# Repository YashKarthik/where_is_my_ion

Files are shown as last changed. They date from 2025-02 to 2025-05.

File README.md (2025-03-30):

# Where is my ION???

## LED <-> Driver assignment

1. Driver 1 - 16
    + [x] 1: Conestoga Mall
    + [x] 2: conn to northfield
    + [x] 1: Northfield
    + [x] 3: northfield to r&t
    + [x] 1: R & T
    + [x] 2: r&t to uw
    + [x] 1: UW
    + [x] 1: uw to laurier-waterloo park
    + [x] 1: Laurier-Waterloo Park Stn.
    + [x] 1: laurier-waterloo park to willis way
    + [x] 1: Willis Way Stn.
    + [x] 1: Allen Stn.

2. Driver 2 - 16
    + [x] 1: allen to grh
    + [x] 1: GRH Stn.
    + [x] 2: grh to central
    + [x] 1: Central Stn.
    + [x] 1: Victoria Stn.
    + [x] 1: Queen Stn.
    + [x] 1: Kitchener-Market Stn.
    + [x] 2: kitchener-market to borden
    + [x] 1: Borden Stn.
    + [x] 2: borden to mill
    + [x] 1: Mill Stn.
    + 
    +

3. Driver 3 - 16
    + [x] 3: mill to block line
    + [x] 1: Block Line Stn.
    + [x] 3: block line to fairway
    + [x] 1: Fairway Stn.
-----------reverse
    + [x] 1: Fairway Stn.
    + [x] 3: fairway to block line
    + [x] 1: Block Line Stn.
    + [x] 3: block line to mill

4. Driver 4 - 16
    + [x] 1: Mill Stn.
    + [x] 1: mill to borden
    + [x] 1: Borden Stn.
    + [x] 2: borden to kitchener-market
    + [x] 1: Kitchener-Market Stn.
    + [x] 0: kitchener-market to frederick
    + [x] 1: Frederick Stn.
    + [x] 0: frederick to kitchener city hall
    + [x] 1: Kitchener City Hall Stn.
    + [x] 0: kitchener city hall to central station
    + [x] 1: Central Stn.
    + [x] 2: central to grand river hospital
    + [x] 1: Grand River Hospital Stn.
    + [x] 1: grand river hospital to allen
    + [x] 1: Allen Stn.
    + [x] 0: allen to waterloo public square
    + [x] 1: Waterloo Public Square Stn.
    + [x] 1: waterloo public square to laurier-waterloo park

5. Driver 5 - 14
    + [x] 1: Laurier-Waterloo Park Stn.
    + [x] 1: laurier-waterloo park to university of waterloo
    + [x] 1: University of Waterloo Stn.
    + [x] 2: university of waterloo to research & tech
    + [x] 1: Research & Tech Stn.
    + [x] 3: research & tech to northfield
    + [x] 1: Northfield Stn.
    + [x] 2: northfield to conestoga
    + [x] 1: Conestoga Stn.
    + [x] 1: WIFI (on/off green)

## Num. LED Calculations

- [x] 16 station leds (c -> f) (blue)
- [x] 16 station leds (f -> c) (blue)
- [x] 21 inter-station leds (c -> f) (white)
- [x] 21 inter-station leds (f -> c) (white)
- [x] 1 red/green => 2 leds (power (ON/OFF))
- [x] 1 green wifi (ON/OFF)

= 78/80 used

### Inter-station LEDs

Conestoga to Fairway
- Conestoga to Northfield: 2 leds
- Northfield to Research & Tech: 3 leds
- Research & Tech to University of Waterloo: 2 leds
- University of Waterloo to Laurier-Waterloo Park: 1 led
- Laurier-Waterloo Park to Willis Way: 1 led
- Willis Way to Allen: 0 led
- Allen to Grand River Hospital: 1 led
- Grand River Hospital to Central Station: 2 leds
- Central Station to Victoria Park (0 led)
- Victoria Park to Queen (0 led)
- Queen to Kitchener-Market (0 led)
- Kitchener Market to Borden (2 led)
- Borden to Mill (1 led)
- Mill to Block Line (3 leds)
- Block Line to Fairway (3 ledss)

Fairway to Conestoga
- Fairway to block line (3 leds)
- Block Line to Mill (3 leds)
- Mill to Borden (1 led)
- Borden to Kitchener-Market (2 led)
- Kitchener-Market to Frederick (0 led)
- Frederick to Kitchener City Hall (0 led)
- Kitchener City Hall to Central Station (0 led)
- Central Station to Grand River Hospital:  2 leds
- Grand River Hospital to Allen: 1 led
- Allen to Waterloo Public Sq: 0 led
- Waterloo Public Sq to Laurier-Waterloo Park: 1 led
- Laurier-Waterloo Park to University of Waterloo to : 1 led
- University of Waterloo to Research & Tech:  2 leds
- Research & Tech to Northfield: 3 leds
- Northfield to Conestoga:  2 leds

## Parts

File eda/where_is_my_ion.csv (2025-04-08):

Reference | Qty | Value | DNP | Exclude from BOM | Exclude from Board | Footprint | Datasheet
C1,C8 | 2 | 10 uF/25V |  |  |  | Capacitor_SMD:C_Elec_4x5.4 | ~
C2,C7 | 2 | 1uF/16V |  |  |  | Capacitor_SMD:C_0805_2012Metric | ~
C3,C4 | 2 | 1 uF/50V (NC) |  |  |  | Capacitor_SMD:C_0805_2012Metric | ~
C5 | 1 | 10uF/25V |  |  |  | Capacitor_SMD:C_Elec_4x5.4 | ~
C6 | 1 | 0.1uF/50V |  |  |  | Capacitor_SMD:C_0603_1608Metric | ~
C9,C14 | 2 | 0.1 uF/50V |  |  |  | Capacitor_SMD:C_0603_1608Metric | ~
C10,C11,C16,C17,C18 | 5 | 0.1uF ceramic |  |  |  | Capacitor_SMD:C_0603_1608Metric | ~
C12,C13,C19,C20,C21 | 5 | 10uF |  |  |  | Capacitor_SMD:C_Elec_4x5.4 | ~
C15 | 1 | 10 uFF/25V |  |  |  | Capacitor_SMD:C_Elec_4x5.4 | ~
D1,D2,D3 | 3 | D_TVS_Filled |  |  |  | Diode_SMD:D_SOD-523 | ~
D4 | 1 | D |  |  |  | Diode_SMD:D_SOD-123 | ~
D5,D6,D7,D10,D11,D12,D16,D19,D20,D21,D22,D28,D33,D34,D37,D39,D46,D47,D52,D53,D54,D55,D57,D62,D65,D70,D81,D82,D83,D84 | 30 | LED_STN_BLUE |  |  |  | LED_SMD:LED_0603_1608Metric | ~
D8 | 1 | LED_FETCH_GREEN |  |  |  | LED_SMD:LED_0603_1608Metric | ~
D9,D13,D14,D15,D17,D18,D23,D24,D25,D26,D29,D30,D31,D32,D35,D36,D38,D40,D41,D44,D45,D48,D50,D51,D56,D58,D59,D60,D61,D63,D64,D66,D67,D68,D69,D71,D72,D73,D74,D75,D76,D77,D78,D79,D80 | 45 | LED_INTER_WHITE |  |  |  | LED_SMD:LED_0603_1608Metric | ~
D27 | 1 | RED POWER LED |  |  |  | LED_SMD:LED_0603_1608Metric | ~
D42 | 1 | LED_API_FAIL_RED |  |  |  | LED_SMD:LED_0603_1608Metric | ~
D43 | 1 | LED_MAP_MODE_GREEN |  |  |  | LED_SMD:LED_0603_1608Metric | ~
D49 | 1 | LED_GREEN_WIFI |  |  |  | LED_SMD:LED_0603_1608Metric | ~
J1 | 1 | USB_C_Receptacle_USB2.0_14P |  |  |  | Connector_USB:USB_C_Receptacle_HRO_TYPE-C-31-M-12 | https://www.usb.org/sites/default/files/documents/usb_type-c.zip
Q1,Q2 | 2 | L8050QLT1G |  |  |  | Package_TO_SOT_SMD:TSOT-23 | ~
R1 | 1 | 22.1 K |  |  |  | Resistor_SMD:R_0603_1608Metric | ~
R2 | 1 | 47.5K |  |  |  | Resistor_SMD:R_0603_1608Metric | ~
R3 | 1 | 1K |  |  |  | Resistor_SMD:R_0603_1608Metric | ~
R4,R5,R13,R21 | 4 | 10K |  |  |  | Resistor_SMD:R_0603_1608Metric | ~
R6,R7 | 2 | 5.1K |  |  |  | Resistor_SMD:R_0603_1608Metric | ~
R8,R9 | 2 | 0 |  |  |  | Resistor_SMD:R_0603_1608Metric | ~
R10 | 1 | 10K (NC) |  |  |  | Resistor_SMD:R_0603_1608Metric | ~
R11,R12 | 2 | 4.7K |  |  |  | Resistor_SMD:R_0603_1608Metric | ~
R14,R15,R16,R17 | 4 | 0(1%) |  |  |  | Resistor_SMD:R_0603_1608Metric | ~
R18,R19,R23,R24,R25 | 5 | 931R |  |  |  | Resistor_SMD:R_0603_1608Metric | ~
R20 | 1 | R |  |  |  | Resistor_SMD:R_0603_1608Metric | ~
R22 | 1 | 5.1 K |  |  |  | Resistor_SMD:R_0603_1608Metric | ~
SW1 | 1 | SW_MCU_RESET |  |  |  | TS-1088-AR02016:SW_TS-1088-AR02016_1 | ~
SW2 | 1 | SW_BOOT_SEL |  |  |  | TS-1088-AR02016:SW_TS-1088-AR02016_1 | ~
SW3 | 1 | FORCE_REFRESH |  |  |  | TS-1088-AR02016:SW_TS-1088-AR02016_1 | ~
SW4 | 1 | NEXT_TRAIN |  |  |  | TS-1088-AR02016:SW_TS-1088-AR02016_1 | ~
TP1,TP2,TP3,TP4 | 4 | TestPoint |  |  |  | TestPoint:TestPoint_Pad_D2.0mm | ~
U1 | 1 | CP2102N-Axx-xQFN28 |  |  |  | Package_DFN_QFN:QFN-28-1EP_5x5mm_P0.5mm_EP3.35x3.35mm | https://www.silabs.com/documents/public/data-sheets/cp2102n-datasheet.pdf
U2,U3,U6,U7,U8 | 5 | TLC59116IPWR |  |  |  | TLC59116IPWR:SOP65P640X120-28N
U4 | 1 | ESP32-C3-WROOM-02 |  |  |  | RF_Module:ESP32-C3-WROOM-02 | https://www.espressif.com/sites/default/files/documentation/esp32-c3-wroom-02_datasheet_en.pdf
U5 | 1 | AP2112K-3.3 |  |  |  | Package_TO_SOT_SMD:SOT-23-5 | https://www.diodes.com/assets/Datasheets/AP2112.pdf

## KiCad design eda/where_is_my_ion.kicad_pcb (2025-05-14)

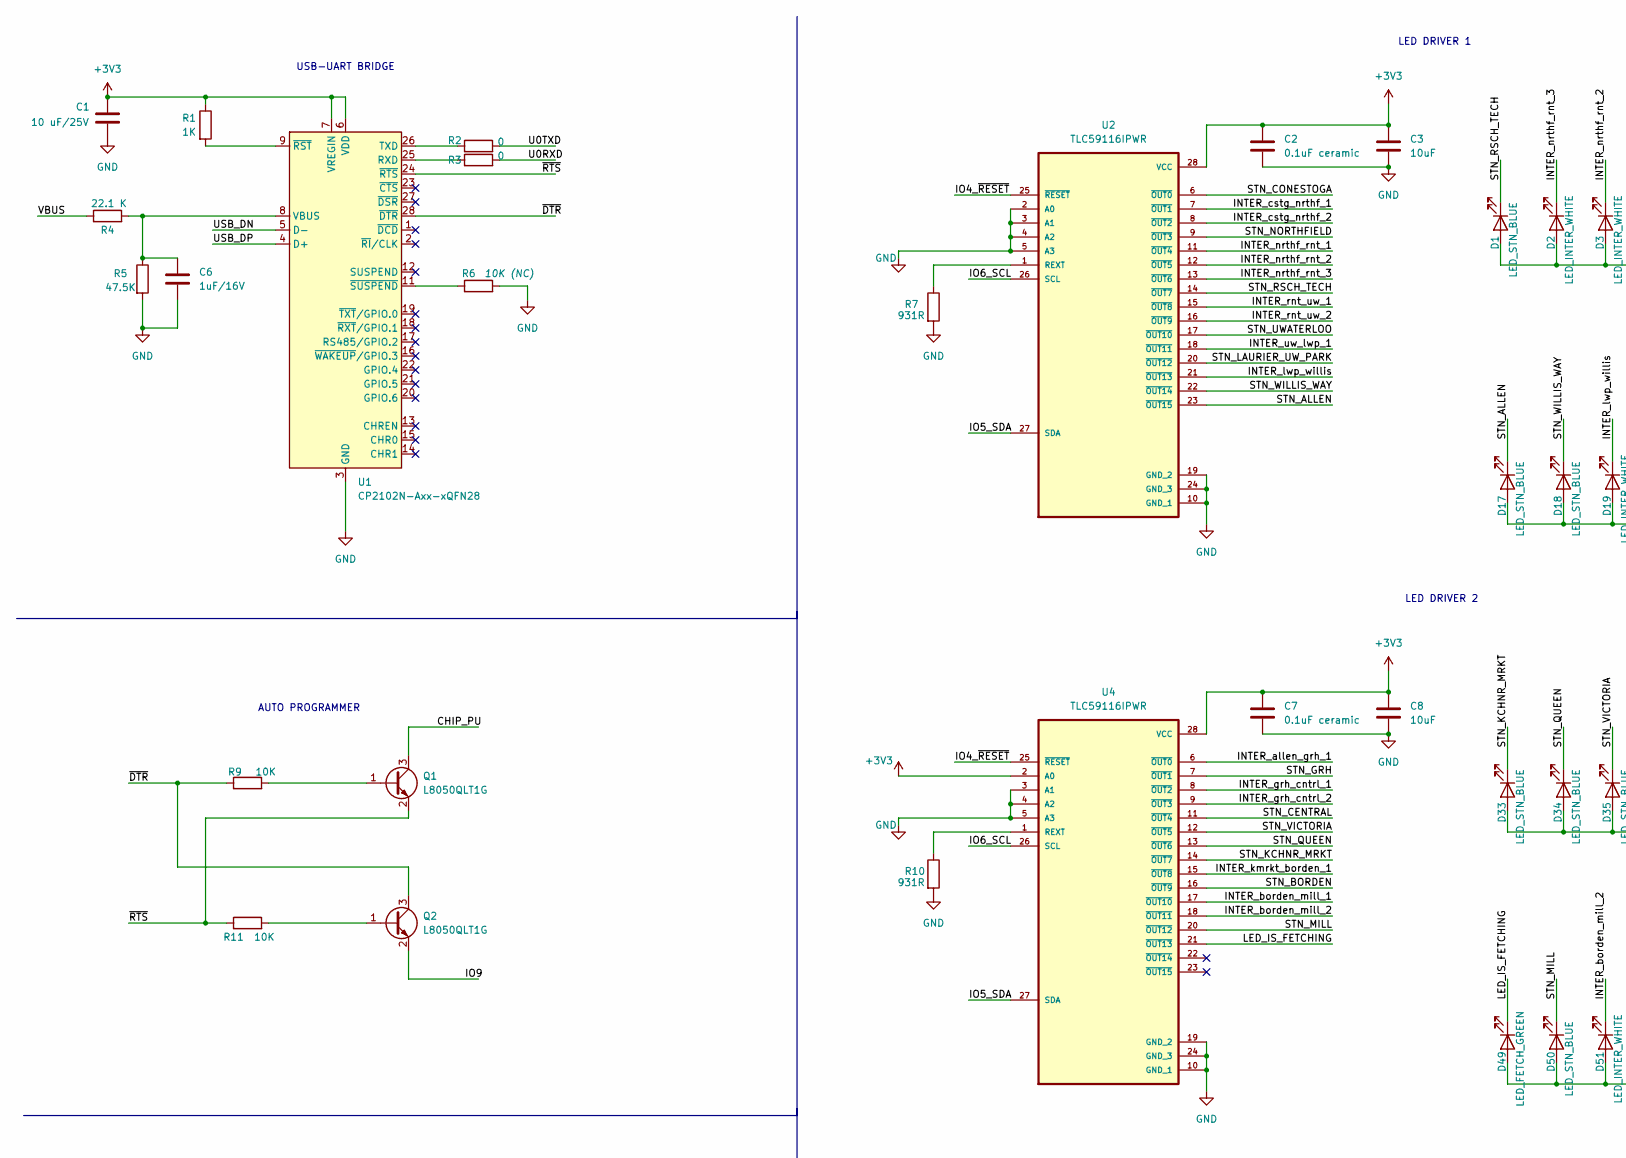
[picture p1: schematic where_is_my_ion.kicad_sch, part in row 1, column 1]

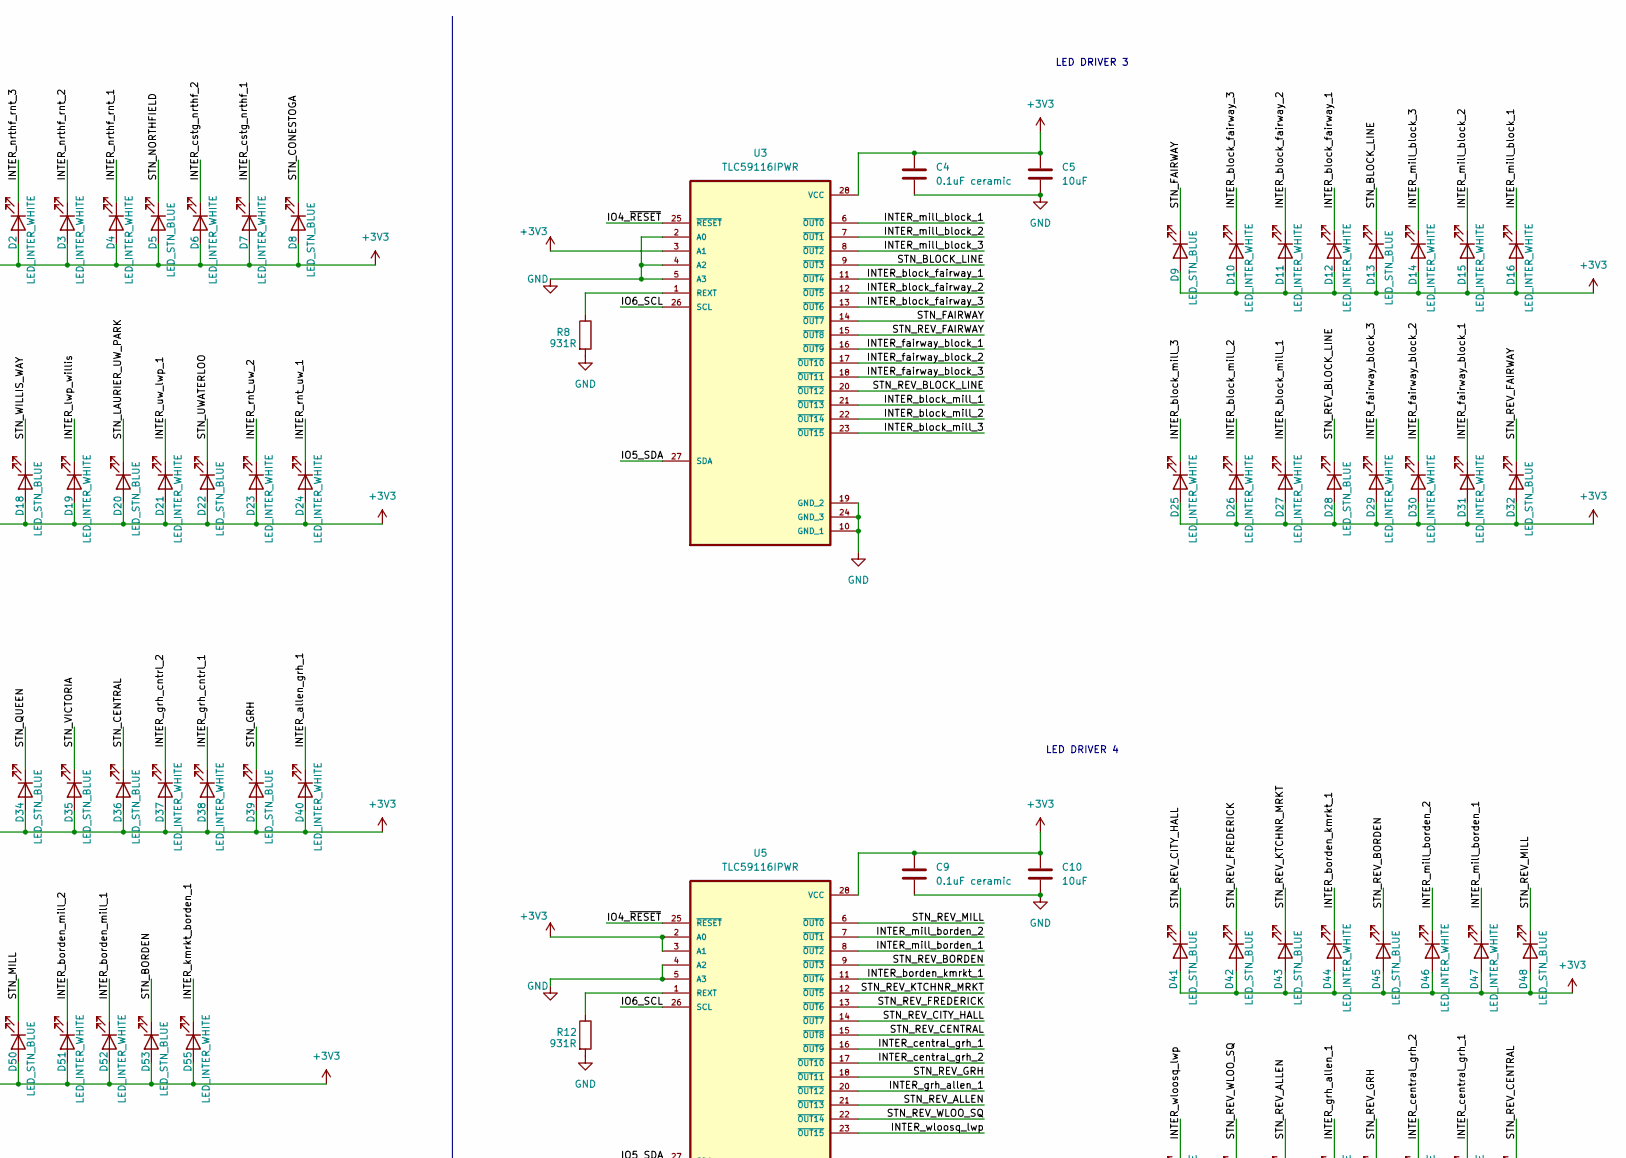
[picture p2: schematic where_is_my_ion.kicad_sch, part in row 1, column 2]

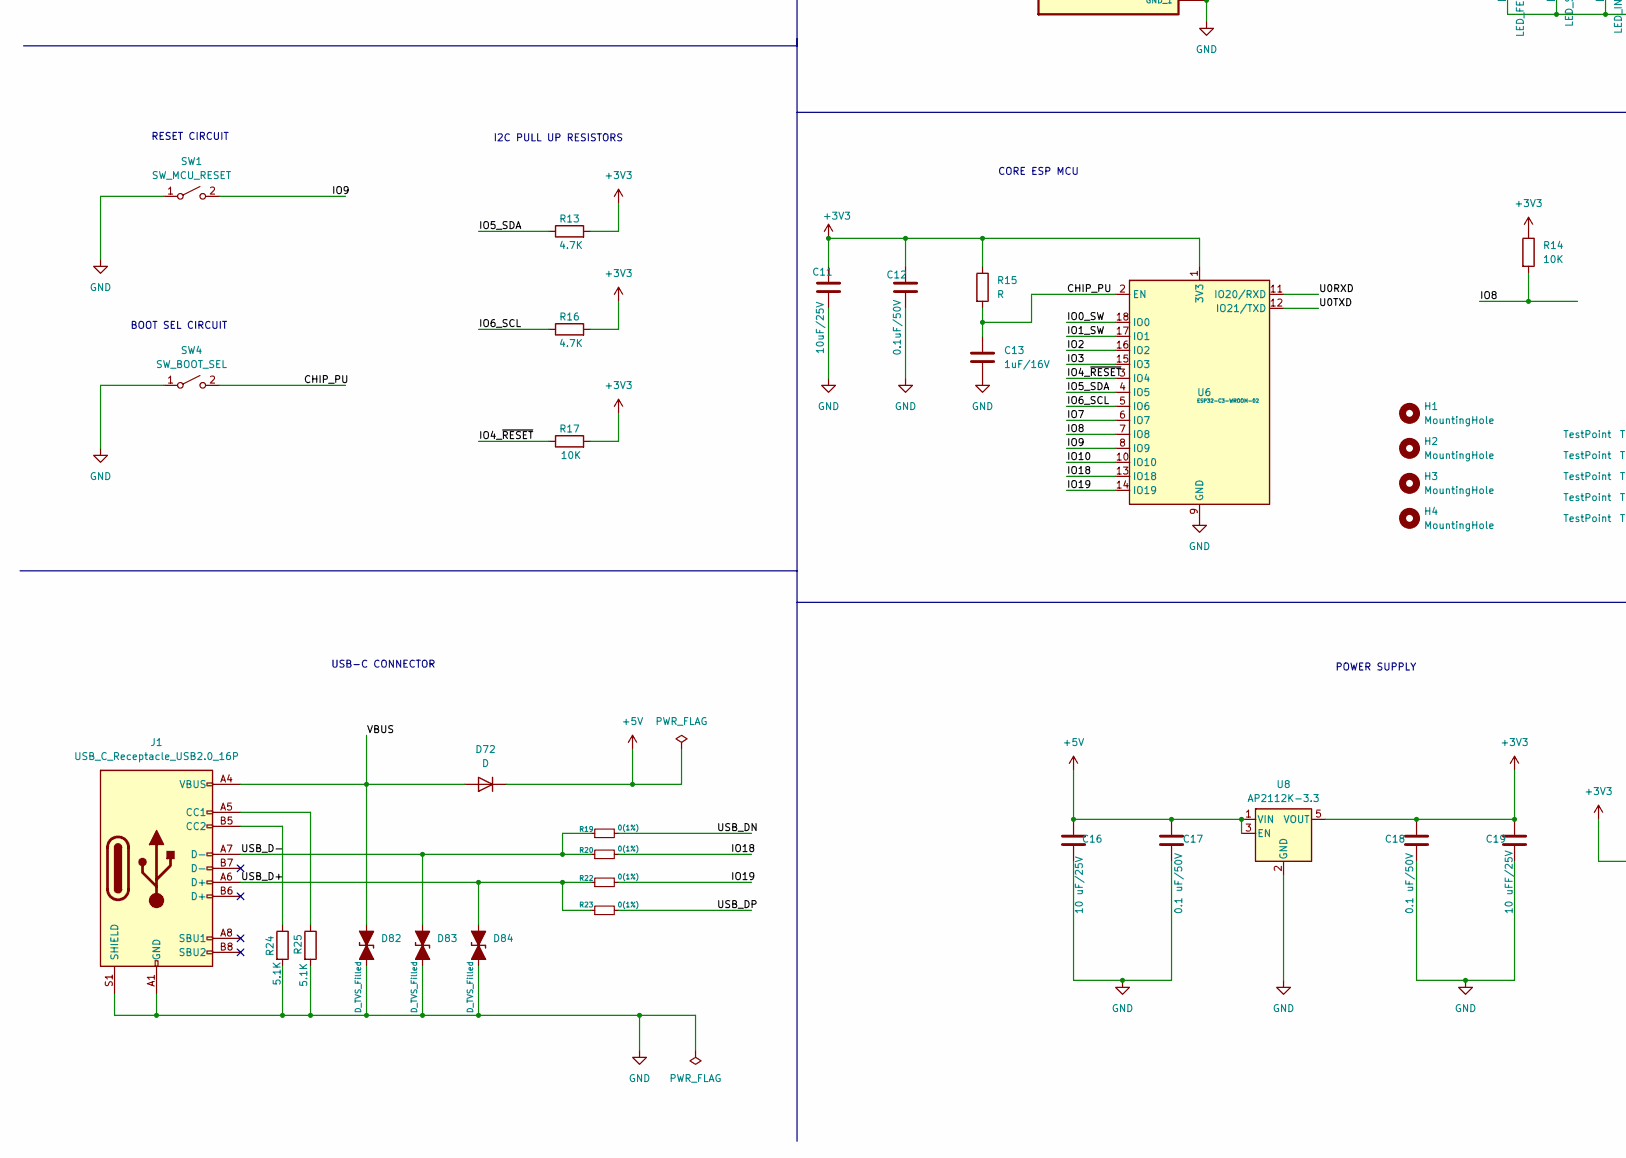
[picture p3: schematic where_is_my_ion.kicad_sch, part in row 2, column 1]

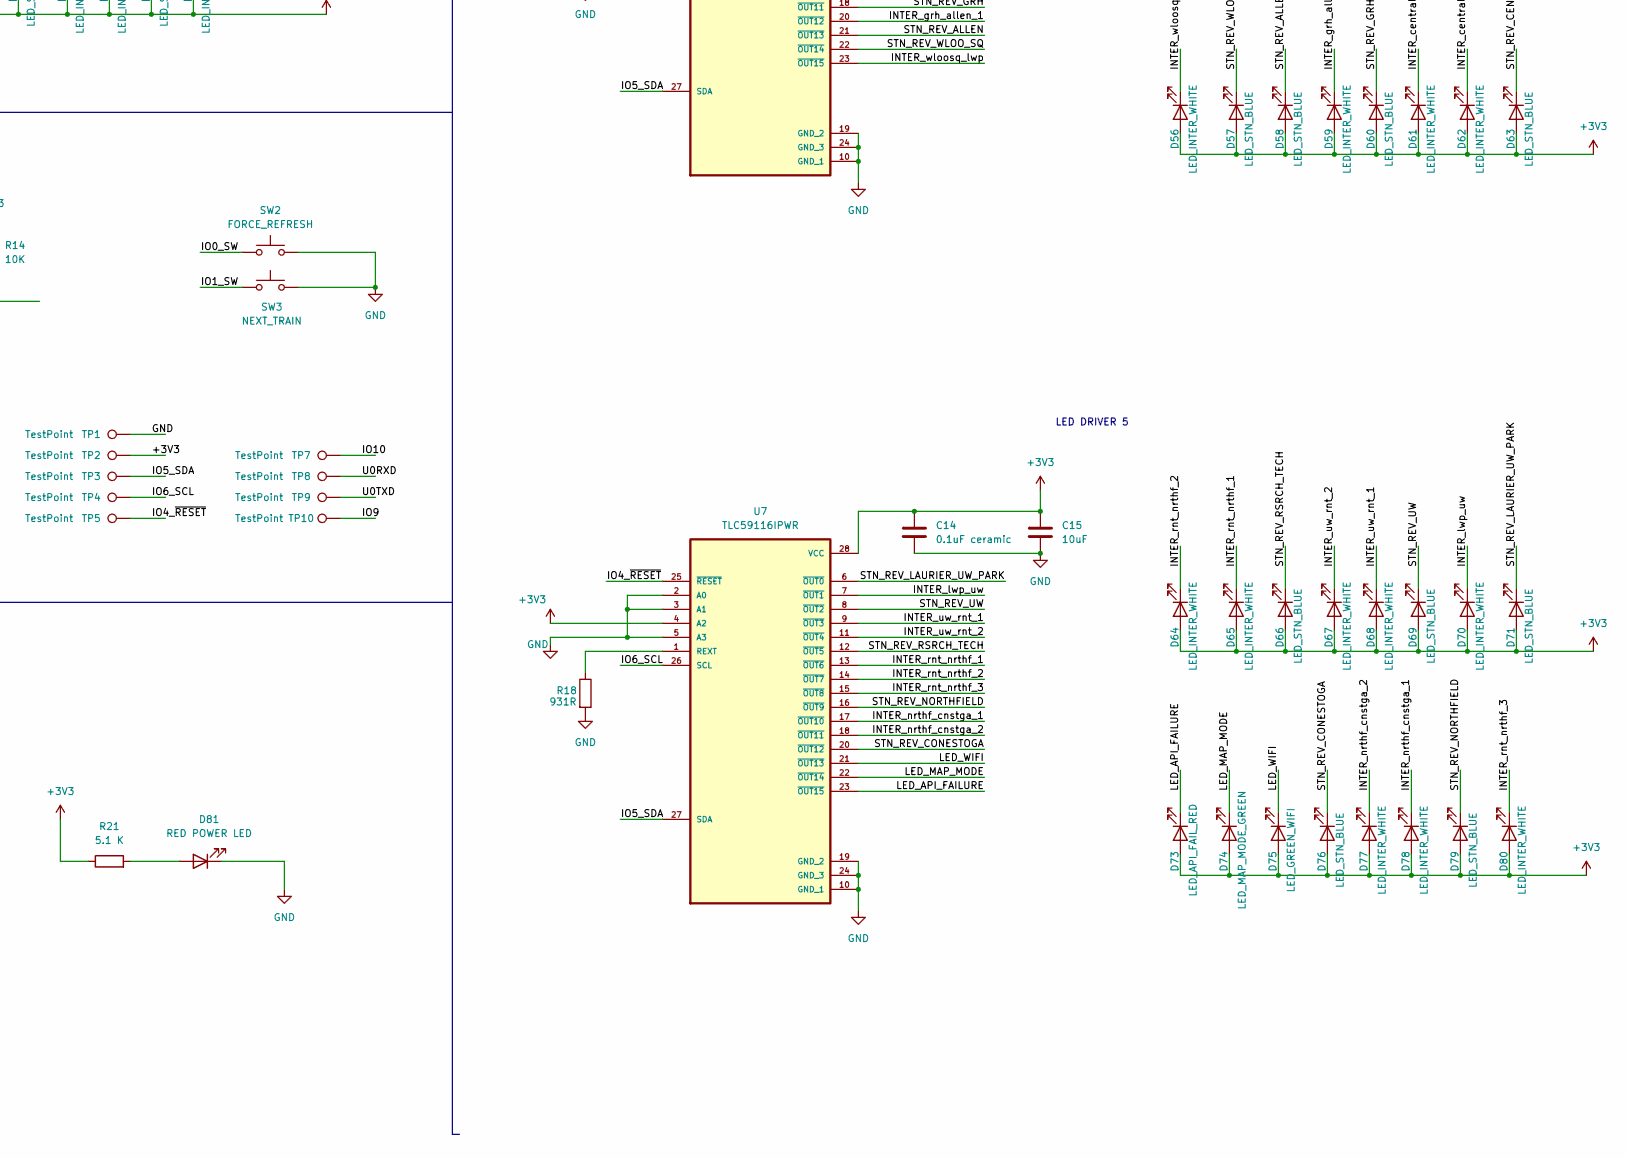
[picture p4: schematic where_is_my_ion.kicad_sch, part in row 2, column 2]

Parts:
C1: 10 uF/25V; CP_EIA-3528-15_AVX-H; LCSC Part Num. C22387953
C2, C4, C7, C9, C14: 0.1uF ceramic; C_0603_1608Metric
C3, C5, C8, C10, C15: 10uF; CP_EIA-3528-15_AVX-H
C6, C13: 1uF/16V; C_0805_2012Metric; LCSC Part Num. C24123
C11: 10uF/25V; CP_EIA-3528-15_AVX-H; LCSC Part Num. C22387953
C12: 0.1uF/50V; C_0603_1608Metric; LCSC Part Num. C3011652
C16: 10 uF/25V; CP_EIA-3528-15_AVX-H
C17, C18: 0.1 uF/50V; C_0603_1608Metric
C19: 10 uFF/25V; CP_EIA-3528-15_AVX-H
D1: LED_STN_BLUE; LED_0603_1608Metric; LCSC Part Num. C497940
D2: LED_INTER_WHITE; LED_0603_1608Metric; LCSC Part Num. C965808
D3, D4, D6, D7, D10, D11, D12, D14, D15, D16, D19, D21, D23, D24, D25, D26, D27, D29, D30, D31, D37, D38, D40, D44, D46, D47, D51, D52, D55, D56, D59, D61, D62, D64, D65, D67, D68, D70, D77, D78, D80: LED_INTER_WHITE; LED_0603_1608Metric
D5, D8, D9, D13, D17, D18, D20, D22, D28, D32, D33, D34, D35, D36, D39, D41, D42, D43, D45, D48, D50, D53, D57, D58, D60, D63, D66, D69, D71, D76, D79: LED_STN_BLUE; LED_0603_1608Metric
D49: LED_FETCH_GREEN; LED_0603_1608Metric; LCSC Part Num. C7429914
D72: D; D_SOD-123; LCSC Part Num. C82544
D73: LED_API_FAIL_RED; LED_0603_1608Metric
D74: LED_MAP_MODE_GREEN; LED_0603_1608Metric
D75: LED_GREEN_WIFI; LED_0603_1608Metric
D81: RED POWER LED; LED_0603_1608Metric; LCSC Part Num. C965799
D82: D_TVS_Filled; D_SOD-523; LCSC Part Num. C383211
D83, D84: D_TVS_Filled; D_SOD-523
H1, H2, H3, H4: MountingHole; MountingHole_2.2mm_M2
J1: USB_C_Receptacle_USB2.0_16P; USB_C_Receptacle_HRO_TYPE-C-31-M-12
Q1, Q2: L8050QLT1G; SOT-23
R1: 1K; R_0603_1608Metric; LCSC Part Num. C22548
R2, R3: 0; R_0603_1608Metric
R4: 22.1 K; R_0603_1608Metric; LCSC Part Num. C137768
R5: 47.5K; R_0603_1608Metric; LCSC Part Num. C2933225
R6: 10K (NC); R_0603_1608Metric
R7, R8, R10, R12, R18: 931R; R_0603_1608Metric
R9, R11, R14, R17: 10K; R_0603_1608Metric
R13, R16: 4.7K; R_0603_1608Metric
R15: R; R_0603_1608Metric
R19, R20, R22, R23: 0(1%); R_0603_1608Metric
R21: 5.1 K; R_0603_1608Metric
R24, R25: 5.1K; R_0603_1608Metric
SW1: SW_MCU_RESET; SW_TS-1088-AR02016_1
SW2: FORCE_REFRESH; SW_TS-1088-AR02016_1
SW3: NEXT_TRAIN; SW_TS-1088-AR02016_1
SW4: SW_BOOT_SEL; SW_TS-1088-AR02016_1
TP1, TP2, TP3, TP4, TP5, TP7, TP8, TP9, TP10: TestPoint; TestPoint_Pad_D2.0mm
U1: CP2102N-Axx-xQFN28; QFN-28-1EP_5x5mm_P0.5mm_EP3.35x3.35mm
U2, U3, U4, U5, U7: TLC59116IPWR; SOP65P640X120-28N
U6: ESP32-C3-WROOM-02
U8: AP2112K-3.3; SOT-23-5

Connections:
+3V3: C1.1, C2.1, C3.1, C4.1, C5.1, C7.1, C8.1, C9.1, C10.1, C11.1, C12.1, C14.1, C15.1, C18.2, C19.1, D1.2 (A), D2.2 (A), D3.2 (A), D4.2 (A), D5.2 (A), D6.2 (A), D7.2 (A), D8.2 (A), D9.2 (A), D10.2 (A), D11.2 (A), D12.2 (A), D13.2 (A), D14.2 (A), D15.2 (A), D16.2 (A), D17.2 (A), D18.2 (A), D19.2 (A), D20.2 (A), D21.2 (A), D22.2 (A), D23.2 (A), D24.2 (A), D25.2 (A), D26.2 (A), D27.2 (A), D28.2 (A), D29.2 (A), D30.2 (A), D31.2 (A), D32.2 (A), D33.2 (A), D34.2 (A), D35.2 (A), D36.2 (A), D37.2 (A), D38.2 (A), D39.2 (A), D40.2 (A), D41.2 (A), D42.2 (A), D43.2 (A), D44.2 (A), D45.2 (A), D46.2 (A), D47.2 (A), D48.2 (A), D49.2 (A), D50.2 (A), D51.2 (A), D52.2 (A), D53.2 (A), D55.2 (A), D56.2 (A), D57.2 (A), D58.2 (A), D59.2 (A), D60.2 (A), D61.2 (A), D62.2 (A), D63.2 (A), D64.2 (A), D65.2 (A), D66.2 (A), D67.2 (A), D68.2 (A), D69.2 (A), D70.2 (A), D71.2 (A), D73.2 (A), D74.2 (A), D75.2 (A), D76.2 (A), D77.2 (A), D78.2 (A), D79.2 (A), D80.2 (A), R1.1, R13.2, R14.1, R15.1, R16.2, R17.2, R21.1, TP2.1, U1.6 (VDD), U1.7 (VREGIN), U2.28 (VCC), U3.3 (A1), U3.28 (VCC), U4.2 (A0), U4.28 (VCC), U5.2 (A0), U5.3 (A1), U5.28 (VCC), U6.1 (3V3), U7.4 (A2), U7.28 (VCC), U8.5 (VOUT)
+5V: C16.1, C17.2, D72.1 (K), U8.1 (VIN), U8.3 (EN)
/CHIP_PU: C13.1, Q1.3 (C), R15.2, SW4.2 (B), U6.2 (EN)
/INTER_allen_grh_1: D40.1 (K), U4.6 (~OUT0)
/INTER_block_fairway_1: D12.1 (K), U3.11 (~OUT4)
/INTER_block_fairway_2: D11.1 (K), U3.12 (~OUT5)
/INTER_block_fairway_3: D10.1 (K), U3.13 (~OUT6)
/INTER_block_mill_1: D27.1 (K), U3.21 (~OUT13)
/INTER_block_mill_2: D26.1 (K), U3.22 (~OUT14)
/INTER_block_mill_3: D25.1 (K), U3.23 (~OUT15)
/INTER_borden_kmrkt_1: D44.1 (K), U5.11 (~OUT4)
/INTER_borden_mill_1: D52.1 (K), U4.17 (~OUT10)
/INTER_borden_mill_2: D51.1 (K), U4.18 (~OUT11)
/INTER_central_grh_1: D62.1 (K), U5.16 (~OUT9)
/INTER_central_grh_2: D61.1 (K), U5.17 (~OUT10)
/INTER_cstg_nrthf_1: D7.1 (K), U2.7 (~OUT1)
/INTER_cstg_nrthf_2: D6.1 (K), U2.8 (~OUT2)
/INTER_fairway_block_1: D31.1 (K), U3.16 (~OUT9)
/INTER_fairway_block_2: D30.1 (K), U3.17 (~OUT10)
/INTER_fairway_block_3: D29.1 (K), U3.18 (~OUT11)
/INTER_grh_allen_1: D59.1 (K), U5.20 (~OUT12)
/INTER_grh_cntrl_1: D38.1 (K), U4.8 (~OUT2)
/INTER_grh_cntrl_2: D37.1 (K), U4.9 (~OUT3)
/INTER_kmrkt_borden_1: D55.1 (K), U4.15 (~OUT8)
/INTER_lwp_uw: D70.1 (K), U7.7 (~OUT1)
/INTER_lwp_willis: D19.1 (K), U2.21 (~OUT13)
/INTER_mill_block_1: D16.1 (K), U3.6 (~OUT0)
/INTER_mill_block_2: D15.1 (K), U3.7 (~OUT1)
/INTER_mill_block_3: D14.1 (K), U3.8 (~OUT2)
/INTER_mill_borden_1: D47.1 (K), U5.8 (~OUT2)
/INTER_mill_borden_2: D46.1 (K), U5.7 (~OUT1)
/INTER_nrthf_cnstga_1: D78.1 (K), U7.17 (~OUT10)
/INTER_nrthf_cnstga_2: D77.1 (K), U7.18 (~OUT11)
/INTER_nrthf_rnt_1: D4.1 (K), U2.11 (~OUT4)
/INTER_nrthf_rnt_2: D3.1 (K), U2.12 (~OUT5)
/INTER_nrthf_rnt_3: D2.1 (K), U2.13 (~OUT6)
/INTER_rnt_nrthf_1: D65.1 (K), U7.13 (~OUT6)
/INTER_rnt_nrthf_2: D64.1 (K), U7.14 (~OUT7)
/INTER_rnt_nrthf_3: D80.1 (K), U7.15 (~OUT8)
/INTER_rnt_uw_1: D24.1 (K), U2.15 (~OUT8)
/INTER_rnt_uw_2: D23.1 (K), U2.16 (~OUT9)
/INTER_uw_lwp_1: D21.1 (K), U2.18 (~OUT11)
/INTER_uw_rnt_1: D68.1 (K), U7.9 (~OUT3)
/INTER_uw_rnt_2: D67.1 (K), U7.11 (~OUT4)
/INTER_wloosq_lwp: D56.1 (K), U5.23 (~OUT15)
/IO0_SW: SW2.1, U6.18 (IO0)
/IO1_SW: SW3.1, U6.17 (IO1)
/IO2: U6.16 (IO2)
/IO3: U6.15 (IO3)
/IO4_~RESET: R17.1, TP5.1, U2.25 (~RESET), U3.25 (~RESET), U4.25 (~RESET), U5.25 (~RESET), U6.3 (IO4), U7.25 (~RESET)
/IO5_SDA: R13.1, TP3.1, U2.27 (SDA), U3.27 (SDA), U4.27 (SDA), U5.27 (SDA), U6.4 (IO5), U7.27 (SDA)
/IO6_SCL: R16.1, TP4.1, U2.26 (SCL), U3.26 (SCL), U4.26 (SCL), U5.26 (SCL), U6.5 (IO6), U7.26 (SCL)
/IO7: U6.6 (IO7)
/IO8: R14.2, U6.7 (IO8)
/IO9: Q2.2 (E), SW1.2 (B), TP10.1, U6.8 (IO9)
/IO10: TP7.1, U6.10 (IO10)
/IO18: R20.2, U6.13 (IO18)
/IO19: R22.2, U6.14 (IO19)
/LED_API_FAILURE: D73.1 (K), U7.23 (~OUT15)
/LED_IS_FETCHING: D49.1 (K), U4.21 (~OUT13)
/LED_MAP_MODE: D74.1 (K), U7.22 (~OUT14)
/LED_WIFI: D75.1 (K), U7.21 (~OUT13)
/STN_ALLEN: D17.1 (K), U2.23 (~OUT15)
/STN_BLOCK_LINE: D13.1 (K), U3.9 (~OUT3)
/STN_BORDEN: D53.1 (K), U4.16 (~OUT9)
/STN_CENTRAL: D36.1 (K), U4.11 (~OUT4)
/STN_CONESTOGA: D8.1 (K), U2.6 (~OUT0)
/STN_FAIRWAY: D9.1 (K), U3.14 (~OUT7)
/STN_GRH: D39.1 (K), U4.7 (~OUT1)
/STN_KCHNR_MRKT: D33.1 (K), U4.14 (~OUT7)
/STN_LAURIER_UW_PARK: D20.1 (K), U2.20 (~OUT12)
/STN_MILL: D50.1 (K), U4.20 (~OUT12)
/STN_NORTHFIELD: D5.1 (K), U2.9 (~OUT3)
/STN_QUEEN: D34.1 (K), U4.13 (~OUT6)
/STN_REV_ALLEN: D58.1 (K), U5.21 (~OUT13)
/STN_REV_BLOCK_LINE: D28.1 (K), U3.20 (~OUT12)
/STN_REV_BORDEN: D45.1 (K), U5.9 (~OUT3)
/STN_REV_CENTRAL: D63.1 (K), U5.15 (~OUT8)
/STN_REV_CITY_HALL: D41.1 (K), U5.14 (~OUT7)
/STN_REV_CONESTOGA: D76.1 (K), U7.20 (~OUT12)
/STN_REV_FAIRWAY: D32.1 (K), U3.15 (~OUT8)
/STN_REV_FREDERICK: D42.1 (K), U5.13 (~OUT6)
/STN_REV_GRH: D60.1 (K), U5.18 (~OUT11)
/STN_REV_KTCHNR_MRKT: D43.1 (K), U5.12 (~OUT5)
/STN_REV_LAURIER_UW_PARK: D71.1 (K), U7.6 (~OUT0)
/STN_REV_MILL: D48.1 (K), U5.6 (~OUT0)
/STN_REV_NORTHFIELD: D79.1 (K), U7.16 (~OUT9)
/STN_REV_RSRCH_TECH: D66.1 (K), U7.12 (~OUT5)
/STN_REV_UW: D69.1 (K), U7.8 (~OUT2)
/STN_REV_WLOO_SQ: D57.1 (K), U5.22 (~OUT14)
/STN_RSCH_TECH: D1.1 (K), U2.14 (~OUT7)
/STN_UWATERLOO: D22.1 (K), U2.17 (~OUT10)
/STN_VICTORIA: D35.1 (K), U4.12 (~OUT5)
/STN_WILLIS_WAY: D18.1 (K), U2.22 (~OUT14)
/U0RXD: R3.2, TP8.1, U6.11 (IO20/RXD)
/U0TXD: R2.2, TP9.1, U6.12 (IO21/TXD)
/USB_D+: D84.2 (A2), J1.A6 (D+), R22.1, R23.1
/USB_D-: D83.2 (A2), J1.A7 (D-), R19.1, R20.1
/USB_DN: R19.2, U1.5 (D-)
/USB_DP: R23.2, U1.4 (D+)
/VBUS: D72.2 (A), D82.2 (A2), J1.A4 (VBUS), J1.A9 (VBUS), J1.B4 (VBUS), J1.B9 (VBUS), R4.1
/~DTR: Q2.3 (C), R9.1, U1.28 (~DTR)
/~RTS: Q1.2 (E), R11.1, U1.24 (~RTS)
GND: C1.2, C2.2, C3.2, C4.2, C5.2, C6.2, C7.2, C8.2, C9.2, C10.2, C11.2, C12.2, C13.2, C14.2, C15.2, C16.2, C17.1, C18.1, C19.2, D81.1 (K), D82.1 (A1), D83.1 (A1), D84.1 (A1), J1.A1 (GND), J1.A12 (GND), J1.B1 (GND), J1.B12 (GND), J1.S1 (SHIELD), R5.2, R6.2, R7.2, R8.2, R10.2, R12.2, R18.2, R24.2, R25.2, SW1.1 (A), SW2.2, SW3.2, SW4.1 (A), TP1.1, U1.3 (GND), U1.29 (GND), U2.2 (A0), U2.3 (A1), U2.4 (A2), U2.5 (A3), U2.10 (GND_1), U2.19 (GND_2), U2.24 (GND_3), U3.2 (A0), U3.4 (A2), U3.5 (A3), U3.10 (GND_1), U3.19 (GND_2), U3.24 (GND_3), U4.3 (A1), U4.4 (A2), U4.5 (A3), U4.10 (GND_1), U4.19 (GND_2), U4.24 (GND_3), U5.4 (A2), U5.5 (A3), U5.10 (GND_1), U5.19 (GND_2), U5.24 (GND_3), U6.9 (GND), U6.19 (GND), U7.2 (A0), U7.3 (A1), U7.5 (A3), U7.10 (GND_1), U7.19 (GND_2), U7.24 (GND_3), U8.2 (GND)
unnamed: D81.2 (A), R21.2
unnamed: J1.A5 (CC1), R25.1
unnamed: J1.B5 (CC2), R24.1
unnamed: Q1.1 (B), R9.2
unnamed: Q2.1 (B), R11.2
unnamed: R3.1, U1.25 (RXD)
unnamed: R2.1, U1.26 (TXD)
unnamed: C6.1, R4.2, R5.1, U1.8 (VBUS)
unnamed: R1.2, U1.9 (~RST)
unnamed: R6.1, U1.11 (~SUSPEND)
unnamed: R7.1, U2.1 (REXT)
unnamed: R8.1, U3.1 (REXT)
unnamed: R10.1, U4.1 (REXT)
unnamed: R12.1, U5.1 (REXT)
unnamed: R18.1, U7.1 (REXT)

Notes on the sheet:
USB-C CONNECTOR
BOOT SEL CIRCUIT
AUTO PROGRAMMER
LED DRIVER 1
LED DRIVER 2
RESET CIRCUIT
POWER SUPPLY
LED DRIVER 5
USB-UART BRIDGE
LED DRIVER 4
LED DRIVER 3
I2C PULL UP RESISTORS
CORE ESP MCU

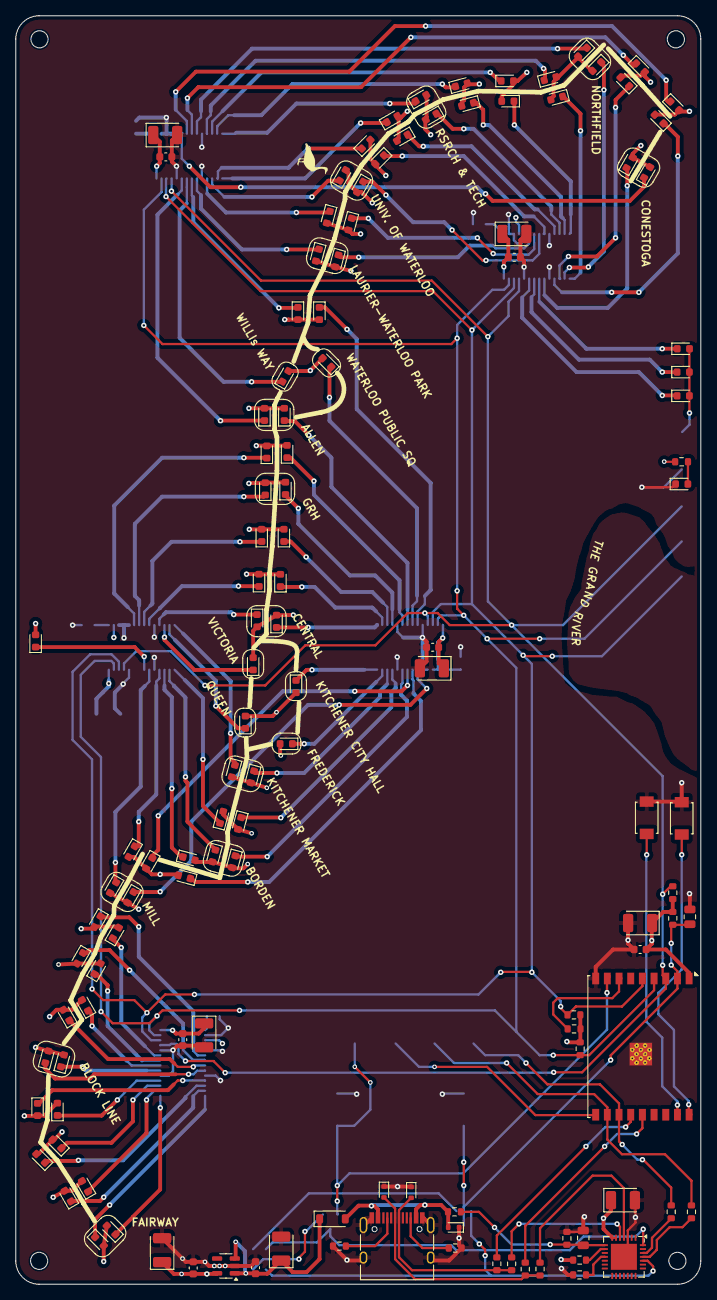
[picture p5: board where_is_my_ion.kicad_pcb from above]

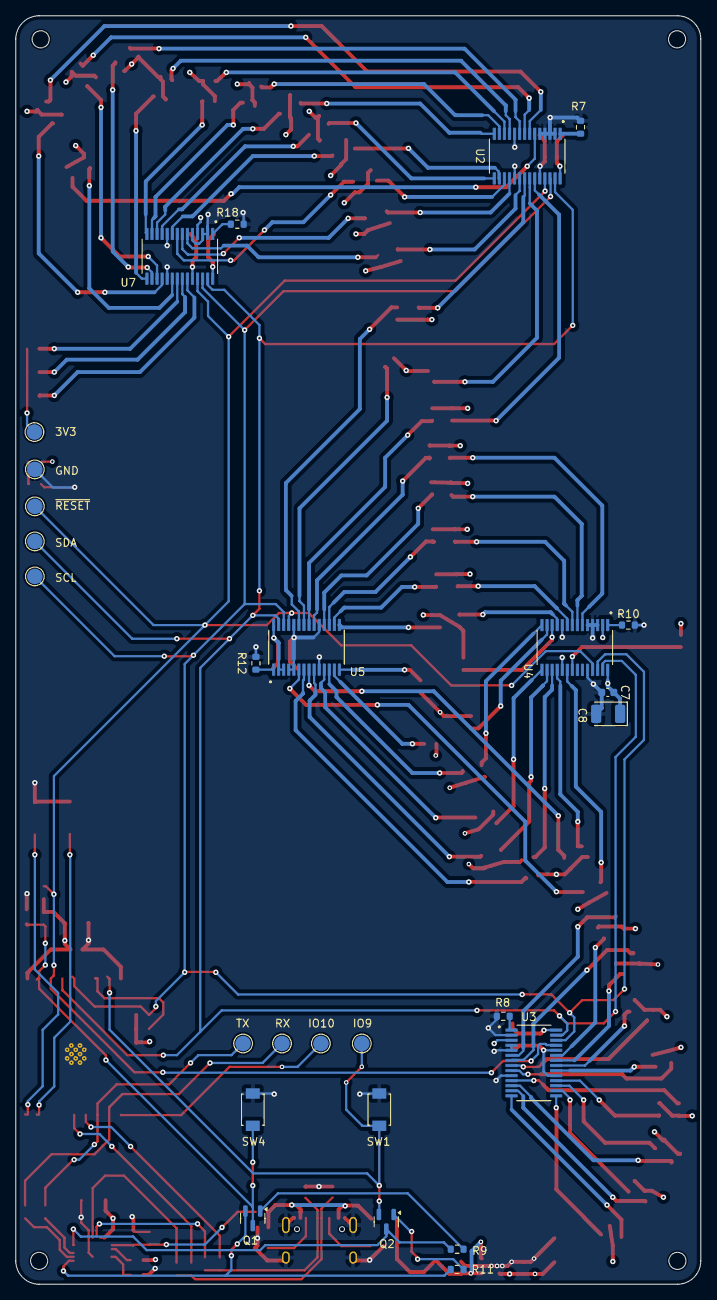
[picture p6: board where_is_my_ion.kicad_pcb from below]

Board: 4 copper layers, 88.0 x 163.0 mm, 155 parts (27 on the bottom side), 116 nets.

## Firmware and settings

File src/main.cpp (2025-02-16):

#include <iostream>
#include <string>
#include <curl/curl.h>
#include "gtfs-realtime.pb.h"
#include "gtfs_loader.h"

const std::string ION_ROUTE_ID = "301";
const std::string GRT_REALTIME_VEHICLE_URL = "https://webapps.regionofwaterloo.ca/api/grt-routes/api/vehiclepositions";

// Callback function to write received data
size_t WriteCallback(void* contents, size_t size, size_t nmemb, std::string* userp) {
  userp->append((char*)contents, size * nmemb);
  return size * nmemb;
}

void check_train_status(const transit_realtime::VehiclePosition& vehicle) {
  if (!vehicle.has_current_status()) {
    std::cerr << "Vehicle does not have current status or stop ID" << '\n';
    return;
  }

  auto status = vehicle.current_status();

  switch (status) {
    case transit_realtime::VehiclePosition_VehicleStopStatus::VehiclePosition_VehicleStopStatus_INCOMING_AT:
      std::cout << "APPROACHING \n";
      break;

    case transit_realtime::VehiclePosition_VehicleStopStatus::VehiclePosition_VehicleStopStatus_STOPPED_AT:
      std::cout << "STOPPED " << '\n';
      break;

    case transit_realtime::VehiclePosition_VehicleStopStatus::VehiclePosition_VehicleStopStatus_IN_TRANSIT_TO:
      std::cout << "IN TRANSIT" << '\n';
      break;
  }
}

int main() {
  CURL* curl = curl_easy_init();
  std::string buffer;

  GTFSLoader loader;
  auto lookup_table = loader.load_gtfs_data("../GRT GTFS/");
  GTFSLoader::print_head(lookup_table);

  if(curl) {
    // Set URL for vehicle positions - use c_str() to get C-style string
    curl_easy_setopt(curl, CURLOPT_URL, GRT_REALTIME_VEHICLE_URL.c_str());
    curl_easy_setopt(curl, CURLOPT_WRITEFUNCTION, WriteCallback);
    curl_easy_setopt(curl, CURLOPT_WRITEDATA, &buffer);

    // Perform request
    CURLcode res = curl_easy_perform(curl);

    if(res != CURLE_OK) {
      std::cerr << "curl_easy_perform() failed: " << curl_easy_strerror(res) << std::endl;
    } else {
      transit_realtime::FeedMessage feed;
      if (feed.ParseFromString(buffer)) {
        // Iterate through entities
        for (const transit_realtime::FeedEntity& entity : feed.entity()) {

          if (entity.has_vehicle() && entity.vehicle().has_trip() && 
            entity.vehicle().trip().route_id() == ION_ROUTE_ID) {
            const auto& vehicle = entity.vehicle();

            if (vehicle.has_position()) {
              vehicle.trip().direction_id() == 0 ? std::cout << "To Conestoga Stn." : std::cout << "To Fairway Stn.";
              std::cout << std::endl;
              std::cout << "ION Train ID: " << entity.id() << std::endl;
              std::cout << "Trip ID:" << vehicle.trip().trip_id() << std::endl;

              std::cout << "Position: " << vehicle.position().latitude() 
                << ", " << vehicle.position().longitude() << std::endl;

              check_train_status(vehicle);

              if (vehicle.has_current_stop_sequence()) {
                std::cout << "Current Stop Sequence: " 
                  << vehicle.current_stop_sequence() << std::endl;
              }

              StopInfo* stop = GTFSLoader::get_stop_info(lookup_table, vehicle.trip().trip_id(), vehicle.current_stop_sequence());
              if (stop) {
                std::cout << "Stop name: " << stop->stop_name << std::endl;
              } else {
                std::cout << "Stop not found" << std::endl;
              }

            }

            std::cout << "-----------------------------------\n" << std::endl;
          }
        }
      } else {
        std::cerr << "Failed to parse protobuf message" << '\n';
      }
    }

    curl_easy_cleanup(curl);
  }

  google::protobuf::ShutdownProtobufLibrary();
  return 0;
}

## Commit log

2025-03-30 schematic done?
    [where_is_my_ion.kicad_pcb, where_is_my_ion.kicad_sch]
2025-03-30 final sch
    [where_is_my_ion.kicad_sch]
2025-04-10 routing is hard
    [where_is_my_ion.kicad_pcb, where_is_my_ion.kicad_sch]
2025-04-17 almost done; might have to redo driver2
    [where_is_my_ion.kicad_pcb, where_is_my_ion.kicad_sch]
2025-04-19 might change
    [where_is_my_ion-B_Cu.gbr, where_is_my_ion-B_Mask.gbr, where_is_my_ion-B_Paste.gbr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]
2025-04-19 side by side layout
    [where_is_my_ion.kicad_pcb, where_is_my_ion.kicad_sch]
2025-04-20 nearly done
    [where_is_my_ion.kicad_pcb, where_is_my_ion.kicad_sch]
2025-04-21 almost done, just silkscreen now
    [where_is_my_ion.kicad_pcb, where_is_my_ion.kicad_sch]
2025-04-22 more silk
    [where_is_my_ion.kicad_pcb]
2025-05-14 probably done
    [where_is_my_ion.kicad_pcb]
